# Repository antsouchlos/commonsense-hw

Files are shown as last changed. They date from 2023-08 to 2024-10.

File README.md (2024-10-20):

# CommonSense

A BLE-based PCB for measuring humidity and temperature.

After cloning, the libraries can be downloaded using
```bash
$ git submodule update --init
```

## PCB




## Schematic



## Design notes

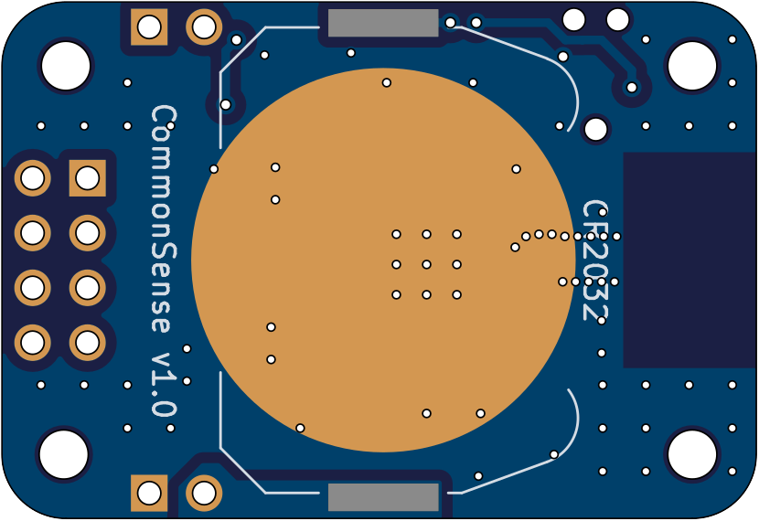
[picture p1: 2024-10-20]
doc/generated/CommonSense-bottom.png

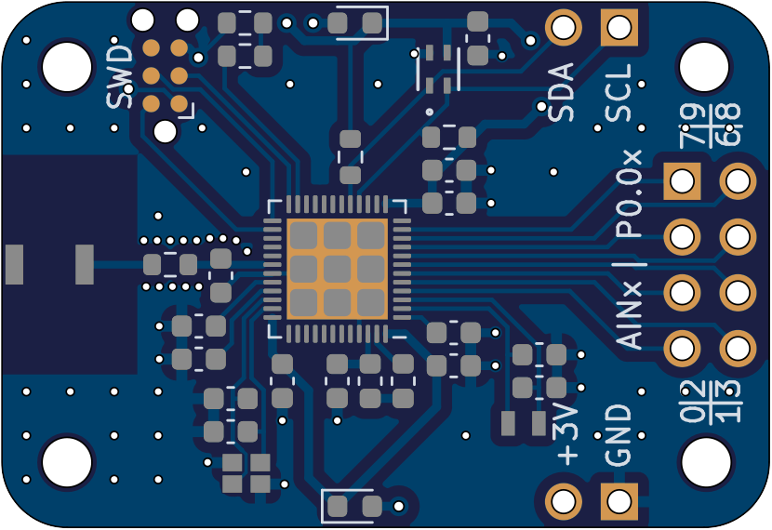
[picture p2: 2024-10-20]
doc/generated/CommonSense-top.png

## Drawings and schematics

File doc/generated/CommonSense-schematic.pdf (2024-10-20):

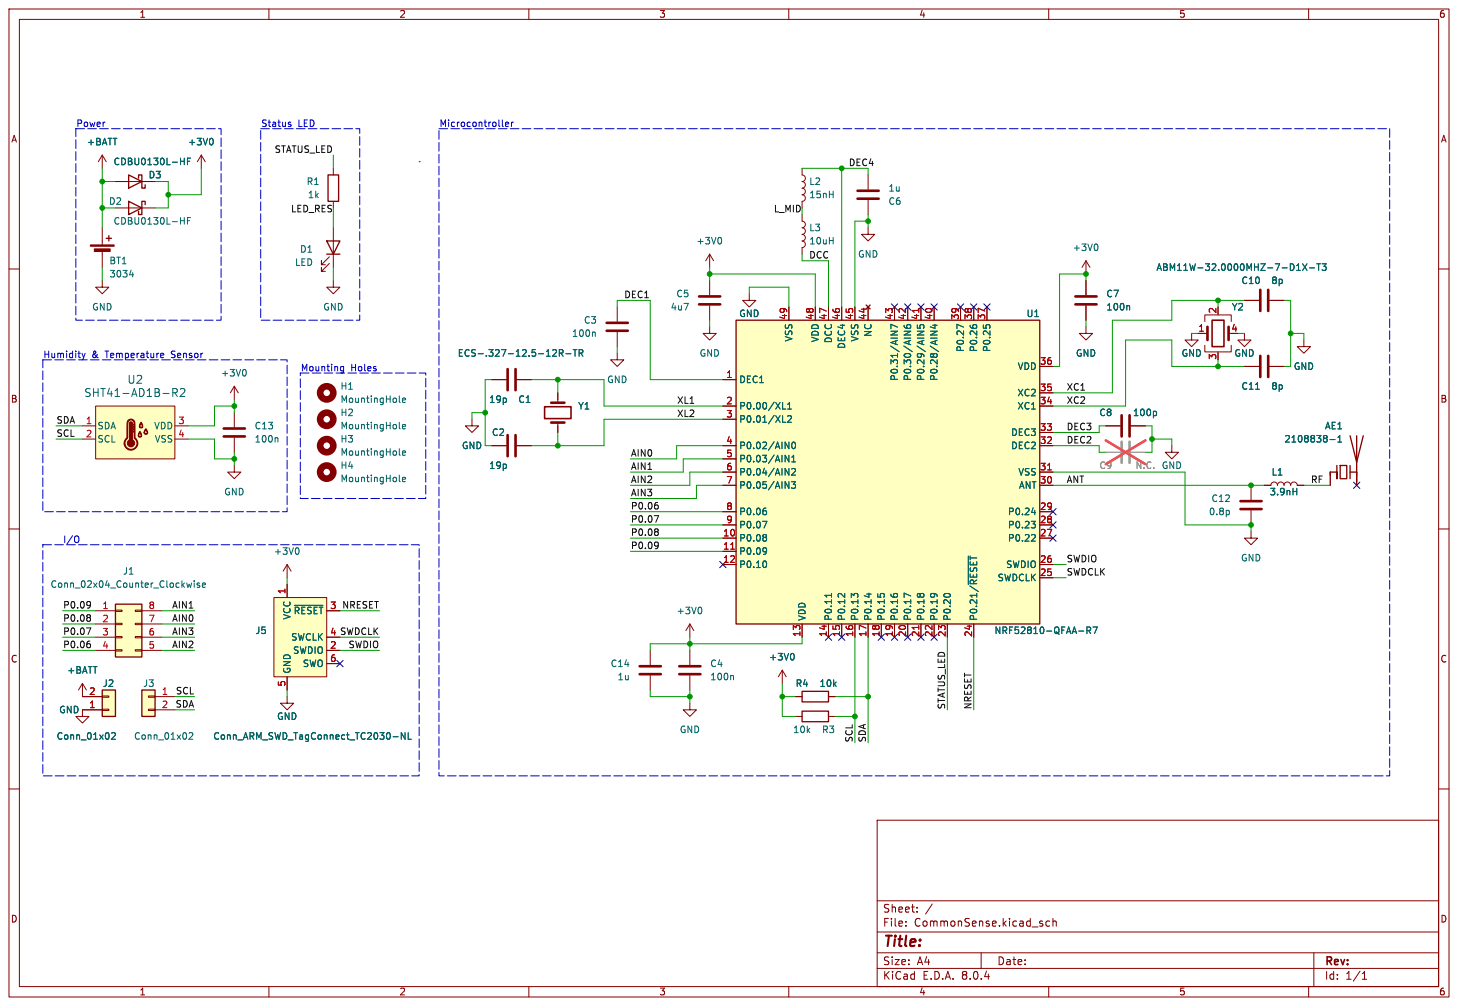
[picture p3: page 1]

1 SWDIO 2 ~{RESET}3 SWCLK 4 GND

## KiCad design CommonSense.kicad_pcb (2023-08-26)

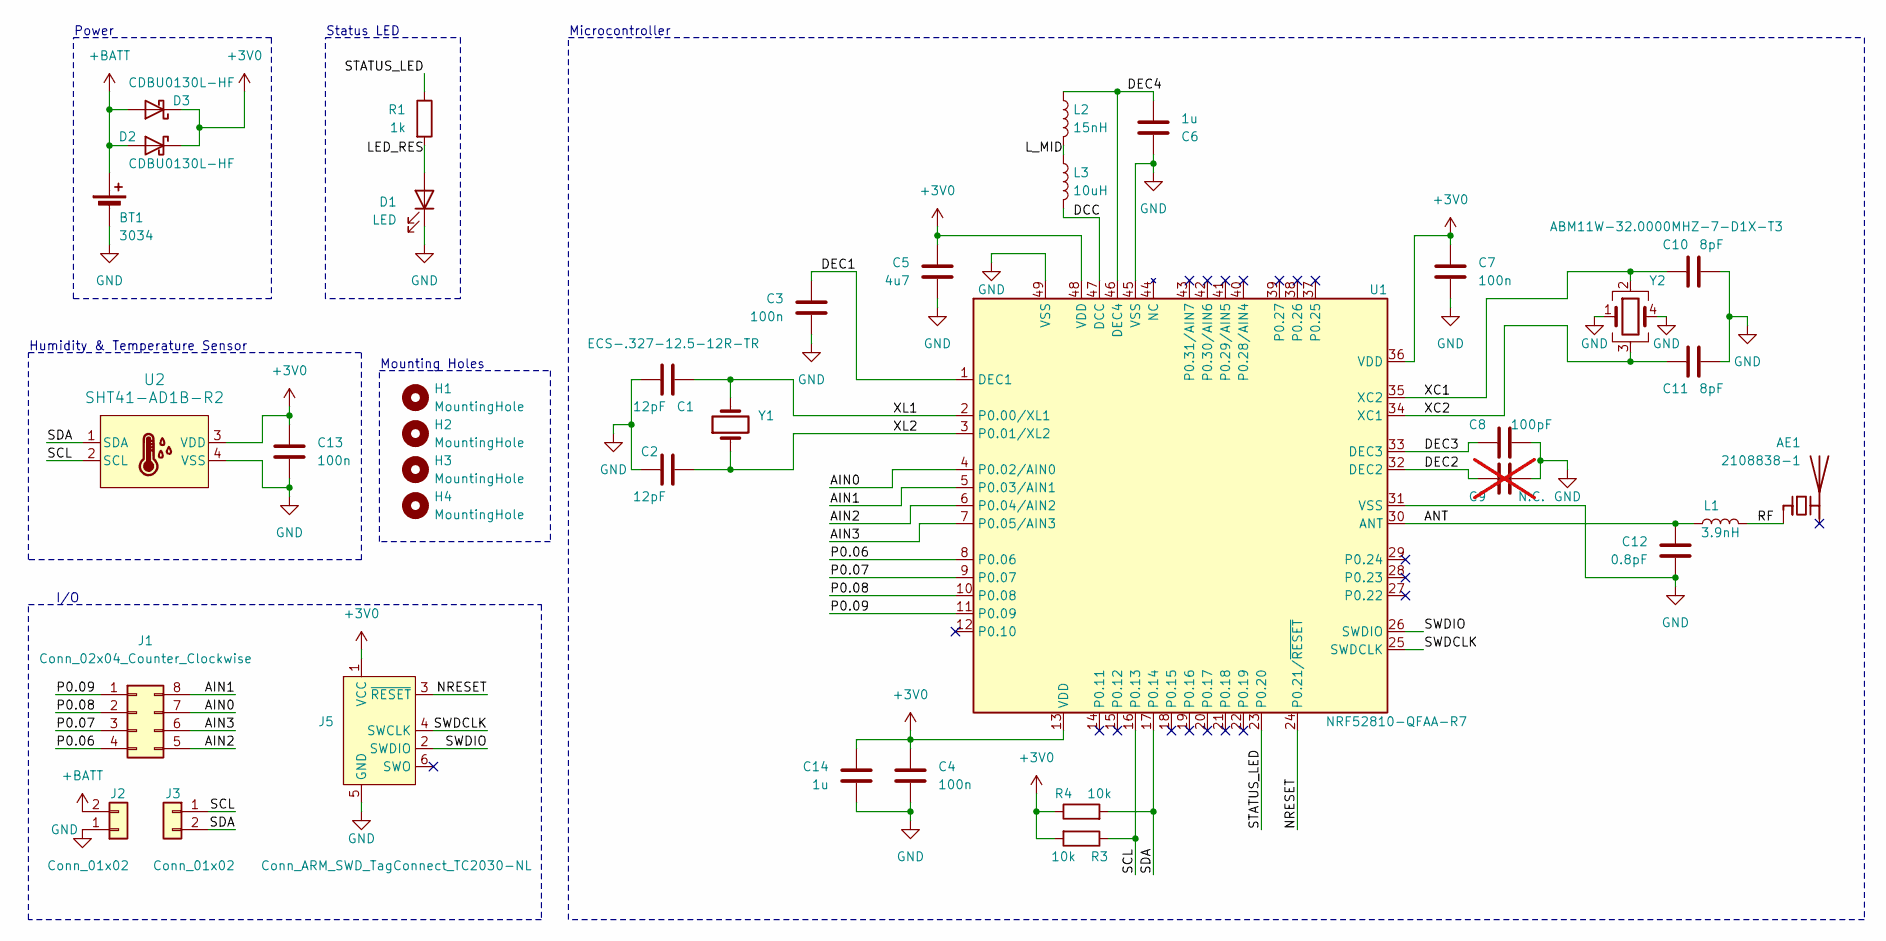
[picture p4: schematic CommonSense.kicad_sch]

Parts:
AE1: 2108838-1
BT1: 3034; BatteryHolder_Keystone_3034_1x20mm
C1, C2: 12pF; C_0603_1608Metric
C3, C4, C7, C13: 100n; C_0603_1608Metric
C5: 4u7; C_0603_1608Metric
C6, C14: 1u; C_0603_1608Metric
C8: 100pF; C_0603_1608Metric
C9: N.C.; C_0603_1608Metric; not fitted
C10, C11: 8pF; C_0603_1608Metric
C12: 0.8pF; C_0603_1608Metric
D1: LED; R_0603_1608Metric
D2, D3: CDBU0130L-HF; D_0603_1608Metric
H1, H2, H3, H4: MountingHole; MountingHole_2.2mm_M2
J1: Conn_02x04_Counter_Clockwise; PinHeader_2x04_P2.54mm_Vertical
J2, J3: Conn_01x02; PinHeader_1x02_P2.54mm_Vertical
J5: Conn_ARM_SWD_TagConnect_TC2030-NL; Tag-Connect_TC2030-IDC-NL_2x03_P1.27mm_Vertical
L1: 3.9nH; R_0603_1608Metric
L2: 15nH; L_0603_1608Metric
L3: 10uH; L_0603_1608Metric
R1: 1k; R_0603_1608Metric
R3, R4: 10k; R_0603_1608Metric
U1: NRF52810-QFAA-R7; QFN-48-1EP_6x6mm_P0.4mm_EP4.6x4.6mm
U2: SHT41-AD1B-R2; DFN4_SHT41_SEN
Y1: ECS-.327-12.5-12R-TR
Y2: ABM11W-32.0000MHZ-7-D1X-T3; ABM11W-30.0000MHZ-7-D1X-T3

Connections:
+3V0: C4.2, C5.2, C7.2, C13.1, C14.2, D2.1 (K), D3.1 (K), J5.1 (VCC), R3.2, R4.1, U1.13 (VDD), U1.36 (VDD), U1.48 (VDD), U2.3 (VDD)
+BATT: BT1.1 (+), D2.2 (A), D3.2 (A), J2.2
/AIN0: J1.7, U1.4 (P0.02/AIN0)
/AIN1: J1.8, U1.5 (P0.03/AIN1)
/AIN2: J1.5, U1.6 (P0.04/AIN2)
/AIN3: J1.6, U1.7 (P0.05/AIN3)
/ANT: C12.2, L1.1, U1.30 (ANT)
/DCC: L3.2, U1.47 (DCC)
/DEC1: C3.2, U1.1 (DEC1)
/DEC2: C9.1, U1.32 (DEC2)
/DEC3: C8.1, U1.33 (DEC3)
/DEC4: C6.1, L2.1, U1.46 (DEC4)
/LED_RES: D1.2 (A), R1.2
/L_MID: L2.2, L3.1
/NRESET: J5.3 (~RESET), U1.24 (P0.21/~RESET)
/P0.06: J1.4, U1.8 (P0.06)
/P0.07: J1.3, U1.9 (P0.07)
/P0.08: J1.2, U1.10 (P0.08)
/P0.09: J1.1, U1.11 (P0.09)
/RF: AE1.1 (FEED), L1.2
/SCL: J3.1, R3.1, U1.16 (P0.13), U2.2 (SCL)
/SDA: J3.2, R4.2, U1.17 (P0.14), U2.1 (SDA)
/STATUS_LED: R1.1, U1.23 (P0.20)
/SWDCLK: J5.4 (SWCLK), U1.25 (SWDCLK)
/SWDIO: J5.2 (SWDIO), U1.26 (SWDIO)
/XC1: C10.1, U1.35 (XC2), Y2.2
/XC2: C11.1, U1.34 (XC1), Y2.3
/XL1: C1.1, U1.2 (P0.00/XL1), Y1.2
/XL2: C2.1, U1.3 (P0.01/XL2), Y1.1
GND: BT1.2 (-), C1.2, C2.2, C3.1, C4.1, C5.1, C6.2, C7.1, C8.2, C9.2, C10.2, C11.2, C12.1, C13.2, C14.1, D1.1 (K), J2.1, J5.5 (GND), U1.31 (VSS), U1.45 (VSS), U1.49 (VSS), U2.4 (VSS), Y2.1, Y2.4

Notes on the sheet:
Humidity & Temperature Sensor
Microcontroller
Mounting Holes
I/O
Status LED
Power

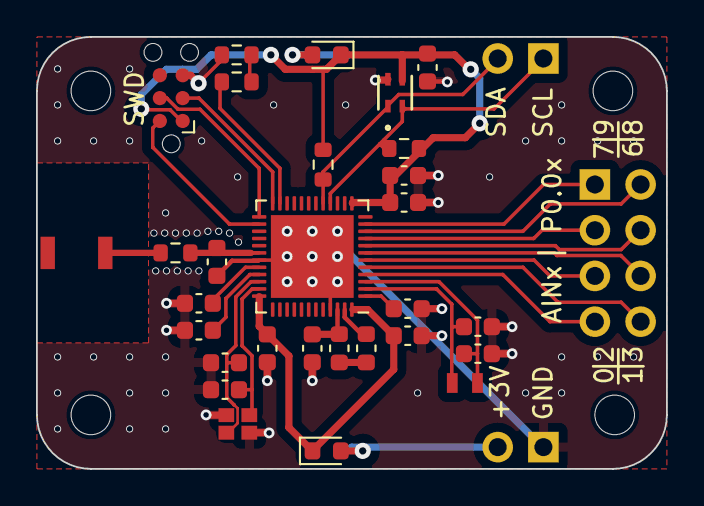
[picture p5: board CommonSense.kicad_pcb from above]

Board: 2 copper layers, 35.0 x 24.0 mm, 37 parts (1 on the bottom side), 30 nets.

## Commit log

2023-07-29 Add project files and gitignore
    [CommonSense.kicad_pcb, CommonSense.kicad_sch]
2023-07-29 Add symbol and footprint libraries to project
2023-07-29 Change librararies of components to encyclopedia galactica
    [CommonSense.kicad_sch]
2023-07-29 Remove net class labels from schematic
    [CommonSense.kicad_sch]
2023-07-30 Replace schematic symbols with new versions from library
    [CommonSense.kicad_sch]
2023-07-30 Create first basic layout
    [CommonSense.kicad_pcb]
2023-07-30 Add missing 3d models
    [CommonSense.kicad_pcb]
2023-07-30 Fix most DRC violations
    [CommonSense.kicad_pcb, CommonSense.kicad_sch]
2023-07-30 Routed all connections
    [CommonSense.kicad_pcb, CommonSense.kicad_sch]
2023-07-30 Minor cosmetic changes
    [CommonSense.kicad_pcb]
2023-07-30 Add version text
    [CommonSense.kicad_pcb]
2023-07-30 Tidy up schematic and add I2C pullup resistors
    [CommonSense.kicad_sch]
2023-07-30 Add I2C pullup resistors to PCB
    [CommonSense.kicad_pcb, CommonSense.kicad_sch]
2023-07-30 Connect IOs and AINs to pin header
    [CommonSense.kicad_sch]
2023-07-30 Start routing connections to pin header
    [CommonSense.kicad_pcb]
2023-07-30 Finish routing ADC in IO pins
    [CommonSense.kicad_pcb, CommonSense.kicad_sch]
2023-07-30 Add SWD connector TODO to schematic
    [CommonSense.kicad_sch]
2023-07-30 Add forgotten ground vias
    [CommonSense.kicad_pcb]
2023-07-30 Add 1x2 pin headers for power and I2C
    [CommonSense.kicad_pcb, CommonSense.kicad_sch]
2023-07-30 Position i2c and power bit headers close to other header; Add text to silk screen
    [CommonSense.kicad_pcb, CommonSense.kicad_sch]
2023-07-30 Move around vias
    [CommonSense.kicad_pcb]
2023-07-30 Add TODO for DC/DC
    [CommonSense.kicad_sch]
2023-07-31 Add SWD connector; Add text on silkscreen
    [CommonSense.kicad_pcb, CommonSense.kicad_sch]
2023-07-31 Increase clearance around trace running under crystal
    [CommonSense.kicad_pcb]
2023-07-31 Remove one status LED and move the other one; Fix text placement of 3V3 GND
    [CommonSense.kicad_pcb, CommonSense.kicad_sch]
2023-07-31 Add inductors and clean up bottom part of PCB
    [CommonSense.kicad_pcb, CommonSense.kicad_sch]
2023-08-01 Add reverse polarity protection diodes; Start cleaning up top part of PCB
    [CommonSense.kicad_pcb, CommonSense.kicad_sch]
2023-08-01 Clean up copper keepout of matching network
    [CommonSense.kicad_pcb]
2023-08-01 Re-route SWD connector
    [CommonSense.kicad_pcb]
2023-08-01 Add additional 1u bypass capacitor
    [CommonSense.kicad_pcb, CommonSense.kicad_sch]
2023-08-01 Route LED and fix silk screen warnings
    [CommonSense.kicad_pcb]
2023-08-01 Add vias to avoid islands
    [CommonSense.kicad_pcb]
2023-08-01 Tidy up schematic
    [CommonSense.kicad_sch]
2023-08-01 Added interactive HTML BOM output directory to gitignore
2023-08-01 Move power pin header to properly align with I2C pin header
    [CommonSense.kicad_pcb]
2023-08-04 Changed Antenna icon to chip antenna and fixed designator
    [CommonSense.kicad_pcb, CommonSense.kicad_sch]
2023-08-04 Add antenna datasheet
    [CommonSense.kicad_sch]
2023-08-05 Change battery holder value to component number
    [CommonSense.kicad_pcb, CommonSense.kicad_sch]
2023-08-05 Check out newest version of library and update component
    [CommonSense.kicad_sch]
2023-08-06 Move I2C pullups closer to nrf chip; Moved I2C lines further appart
    [CommonSense.kicad_pcb]
2023-08-08 Move pin headers to ensure multiple of 2.54mm spacing; Add proper via stitching
    [CommonSense.kicad_pcb]
2023-08-08 Add stitching vias to RF trace
    [CommonSense.kicad_pcb]
2023-08-22 Change crystal capacitor values
    [CommonSense.kicad_sch]
2023-08-26 Add 1k value to LED resistor
    [CommonSense.kicad_sch]
2023-08-26 Update PCB from schematic
    [CommonSense.kicad_pcb]
2023-09-07 Fix component values
    [CommonSense.kicad_sch]
